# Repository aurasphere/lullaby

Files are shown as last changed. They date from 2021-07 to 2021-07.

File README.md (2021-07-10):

# Lullaby
Open source smart music box based on Arduino. It can store a melody inside the EEPROM which can later be played by pressing a button or by sending commands to the serial port. 

## Features
 - programmable, with persistent melody storage
 - supports 4 types of notes (whole, half, quarter, eighth) with relative rests, across 7 octaves. Notes can also be altered and dotted
 - customizable BPM
 - supports any time signature having a denominator of 2, 4 or 8 (e.g. 4/4, 2/2, 6/8...)
 - dedicated [mobile app](https://github.com/aurasphere/lullaby-mobile)
 - real-time playing (can be used as a piano or while composing the melody to store)
 - melody export (useful to save multiple melodies and restore them anytime)
 - optional led randomization on each note played

## Components
 - HC-05 Bluetooth Module
 - Active Buzzer
 - Arduino Nano (or any other compatible board)
 - Button
 - Resistance (1 needed, up to 5 more optional)
 - Leds (optional, up to 5) 
 
## Schematics

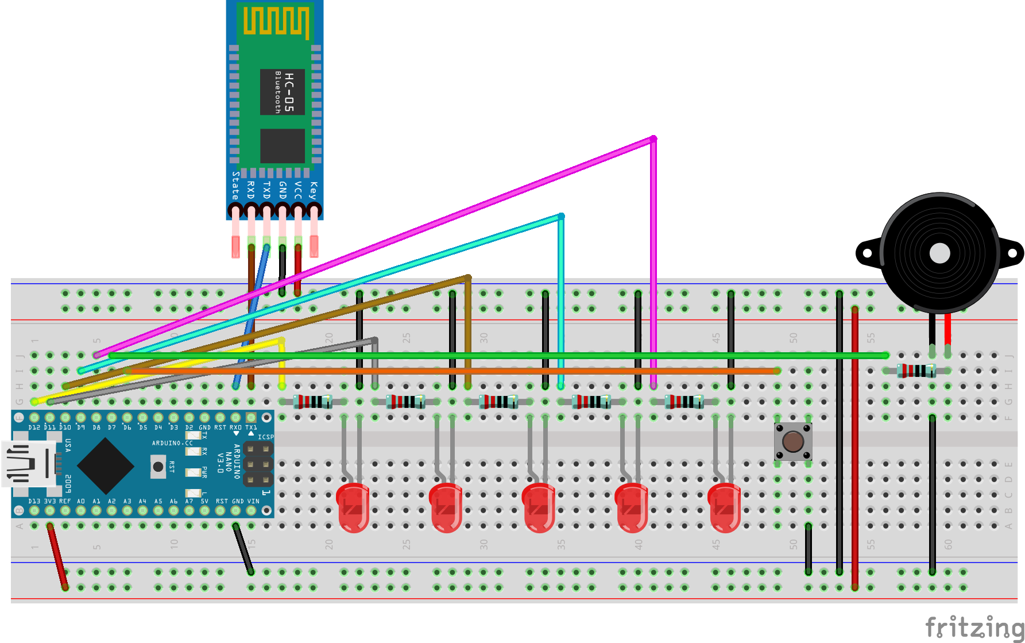
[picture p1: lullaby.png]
Schematics


## Commands

Communication is performed through serial port. Each command starts with an ASCII lowercase character and ends with a newline (```\n```). Some commands also require a melody argument (the encoding is described in the next paragraph). The available commands are the following:

 - **p**, plays the melody currently stored in EEPROM
 - **s(melody)**, saves the given melody into EEPROM
 - **d**, prints the details of the melody stored
 - **e**, exports the given melody in the Lullaby protocol
 - **n(melody)**, plays the given melody
 
## Melody Protocol

Lullaby uses a custom protocol based on hexadecimal bit stuffing. Each melody is represented by appending an header to a sequence of notes:

    <header><note><note><note>...
	
Both the header and the notes have a fixed length of 3 characters, so the length of each encoded melody is guaranteed to be a multiple of 3. The length of any melody is equal to 

    (encodedLength - 3) / 3.

### Header

The melody header contains the BPM and beat unit (e.g. the denominator of the time signature). The BPM is converted to 2 hexadecimal characters (using padding if needed) and then prepended to the beat unit, which is a digit between 1-3:
	  
| Time Signature | Beat Unit |
|:---:|:---:|
| */2 (2/2, 3/2, 4/2...) | 1 |
| */4 (2/4, 4/4, 5/4...) | 2 |
| */8 (3/8, 6/8, 9/8...) | 3 |
	    
For example, given a melody with a time signature of 4/4 and 120 BPM, the resulting header will be ```782```.
	    
### Notes

Each note is represented by 3 hexadecimal characters (1 + 1/2 bytes) containing the following informations (in order):
 - **pitch**, an integer ranging from 0 to 7 (3 bits) with 1 being C (Do) and 7 being B (Si). 0 is a rest
 - **duration**, an integer ranging from 0 to 4, (2 bits) indicating the note duration, according to the table below
 - **octave**, an integer ranging from 1 to 7 (3 bits)
 - **extended**, 0 (false) or 1 (true) (1 bit). Whether the note is dotted or not
 - **altered**, 0 (false) or 1 (true) (1 bit). Whether the note is altered (#) 

| Note |  Duration |
|:---:|:---:|
| Whole 𝅝	 | 0 |
| Half 	  𝅗𝅥 	 | 1 |
| Quarter ♩ | 2 |
| Eight ♪ | 3 |

The pitch, duration and octave are stored into the first byte (2 hex chars) meanwhile the extended and altered flags are stored in the last half byte (1 hex char). All the stuffing is big endian.

For example, we can calculate the value of the note G#5𝅗𝅥 as following:

    (5 << 5) + (1 << 3) + 5 =  173 = 0xAD // pitch + duration + octave, all compressed in 1 byte
    (0 << 3) + (1 << 2) = 4 = 0x4 // extended + altered, all compressed in 1/2 byte
    
And the final result is ```AD4```. So, taking the header we can attach the header we build before to have a complete melody, made up of only one note: ```782AD4```. 

To avoid unexpected behavior, Lullaby allows melodies up to 64 notes by default, but this can be easily configured by changing the ```MAX_MELODY_LENGTH``` property according to your device memory (both EEPROM and SRAM).

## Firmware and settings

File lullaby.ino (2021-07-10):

#include "pitches.h"
#include <avr/eeprom.h>

#define SERIALIZED_EOS_CHAR '\n'
#define SERIALIZED_NOTE_LENGTH 3
#define SERIALIZED_HEADER_LENGTH 3
#define MAX_MELODY_LENGTH 64
// See protocol_handler for info on how this is calculated
#define MESSAGE_BUFFER_SIZE 1 + SERIALIZED_HEADER_LENGTH + (MAX_MELODY_LENGTH * SERIALIZED_NOTE_LENGTH)

#define PRINT_MENU false
#define BAUD_RATE 9600

// Button
#define BUTTON 6
#define BUZZER 7

// Leds
#define WHITE 8
#define BLUE 9
#define GREEN 10
#define YELLOW 11
#define RED 12

// Stored on flash memory to save RAM.
const uint16_t NOTES[] PROGMEM = {NOTE_C1, NOTE_D1, NOTE_E1, NOTE_F1, NOTE_G1, NOTE_A1, NOTE_B1, NOTE_C2, NOTE_D2, NOTE_E2, NOTE_F2, NOTE_G2, NOTE_A2, NOTE_B2, NOTE_C3, NOTE_D3, NOTE_E3, NOTE_F3, NOTE_G3, NOTE_A3, NOTE_B3, NOTE_C4, NOTE_D4, NOTE_E4, NOTE_F4, NOTE_G4, NOTE_A4, NOTE_B4, NOTE_C5, NOTE_D5, NOTE_E5, NOTE_F5, NOTE_G5, NOTE_A5, NOTE_B5, NOTE_C6, NOTE_D6, NOTE_E6, NOTE_F6, NOTE_G6, NOTE_A6, NOTE_B6, NOTE_C7, NOTE_D7, NOTE_E7, NOTE_F7, NOTE_G7, NOTE_A7, NOTE_B7};
const uint16_t NOTES_ALTERED[] PROGMEM = {NOTE_CS1, NOTE_DS1, NOTE_E1, NOTE_FS1, NOTE_GS1, NOTE_AS1, NOTE_B1, NOTE_CS2, NOTE_DS2, NOTE_E2, NOTE_FS2, NOTE_GS2, NOTE_AS2, NOTE_B2, NOTE_CS3, NOTE_DS3, NOTE_E3, NOTE_FS3, NOTE_GS3, NOTE_AS3, NOTE_B3, NOTE_CS4, NOTE_DS4, NOTE_E4, NOTE_FS4, NOTE_GS4, NOTE_AS4, NOTE_B4, NOTE_CS5, NOTE_DS5, NOTE_E5, NOTE_FS5, NOTE_GS5, NOTE_AS5, NOTE_B5, NOTE_CS6, NOTE_DS6, NOTE_E6, NOTE_FS6, NOTE_GS6, NOTE_AS6, NOTE_B6, NOTE_CS7, NOTE_DS7, NOTE_E7, NOTE_FS7, NOTE_GS7, NOTE_AS7, NOTE_B7};

struct Note {
  uint8_t pitch : 3;
  uint8_t duration : 2;
  uint8_t octave : 3;
  boolean extended : 1;
  boolean altered : 1;
};

struct MelodyInfo {
  uint8_t bpm;
  uint8_t beatUnit;
  uint16_t length;
};

void setup() {
  // Open serial for communication.
  Serial.begin(BAUD_RATE);

  if (PRINT_MENU) {
    printMenu();
  }

  // Inizializes LEDS (if available)
  for (uint8_t i = WHITE; i <= RED; i++) {
    pinMode(i, OUTPUT);
  }

  // Inizializes the button
  pinMode(BUTTON, INPUT_PULLUP);
}

void playMelody(Note* melody, MelodyInfo melodyInfo) {
  uint16_t beatMillis = 60000 / melodyInfo.bpm;
  for (uint8_t i = 0; i < melodyInfo.length; i++) {
    Note note = melody[i];
    uint16_t duration = beatMillis * pow(2, note.duration - melodyInfo.beatUnit) * (note.extended ? 1.5 : 1);

    // Pitch of 0 is a rest.
    if (note.pitch == 0) {
      delay(duration);
      clearLeds();
      continue;
    }

    uint16_t pitch = pgm_read_word((note.altered ? NOTES_ALTERED : NOTES) + ((note.pitch - 1)  + (7 * (note.octave - 1))));

    // Plays a note.
    tone(BUZZER, pitch, duration);

    randomizeLeds();

    // Plays the note for the specified duration.
    delay(duration);
  }
  delete[] melody;
  clearLeds();
}


void playMelody() {
  MelodyInfo melodyInfo = loadMelodyInfoFromEeprom();
  Note melody[melodyInfo.length];
  loadMelodyFromEeprom(melodyInfo, melody);
  playMelody(melody, melodyInfo);
}

void loop() {

  // Handles a menu selection.
  if (Serial.available()) {
    handleMenuInput();
  }

  if (digitalRead(BUTTON) == LOW) {
    playMelody();
  }
}

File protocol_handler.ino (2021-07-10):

// Each melody is serialized in the following format:
// 3 chars (2 hex + 1|2|3) = MelodyInfo (or header), containing bpm and beatUnit
// 3 chars per note (hex)
// An header is represented by 3 characters:
// 2 HEX <- bpm
// 1|2|3 <- the beat unit
//        1 = */2 (half note)
//        2 = */4 (quarter note)
//        3 = */8 (eight note)
// Each note is represented by 3 HEX char with the following content:
// 3 bit <- note (0 to 7, 0 is for a rest)
// 2 bit <- duration (0 to 4, see below)
// 3 bit <- octave (1 to 7)
// 1 bit <- extended (true or false)
// 1 bit <- altered (true or false)
// 2 bit <- filler
// Supported durations:
// 0 -> whole note
// 1 -> half note
// 2 -> quarter note
// 3 -> eight note

// Deserialization functions.
MelodyInfo deserializeMelody(char* msgBuffer, Note* melodyBuffer) {
  uint16_t melodyLength = 0;

  // Parses the header first
  char header[4] = {msgBuffer[1], msgBuffer[2], msgBuffer[3]};
  MelodyInfo melodyInfo = deserializeHeader(header);

  // Parses the single notes.
  char nextChar = msgBuffer[4];
  while (nextChar != NULL) {
    uint8_t notePointer = (melodyLength * 3) + 4;
    char noteChar[5] = {msgBuffer[notePointer], msgBuffer[notePointer + 1] , msgBuffer[notePointer + 2]};
    melodyBuffer[melodyLength] = deserializeNote(noteChar);
    melodyLength++;
    nextChar = msgBuffer[notePointer + 3];
  }

  melodyInfo.length = melodyLength;
  return melodyInfo;
}

Note deserializeNote(char* note) {
  char firstByteArray[3] = {note[0], note[1]};
  char secondByteArray[2] = {note[2]};
  uint8_t firstByte = (uint8_t) strtol(firstByteArray, NULL, 16);
  uint8_t secondByte = (uint8_t) strtol(secondByteArray, NULL, 16);
  return  (Note) {
    (firstByte & (0b111 << 5)) >> 5,
    (firstByte & (0b11 << 3)) >> 3,
    firstByte & 0b111,
    (secondByte & (1 << 3)) != 0,
    (secondByte & (1 << 2)) != 0
  };
}

MelodyInfo deserializeHeader(char* header) {
  char bpmHex[3] = {header[0], header[1]};
  uint8_t bpm = (uint8_t) strtol(bpmHex, NULL, 16);
  uint8_t beatNote = (uint8_t) strtol(&header[2], NULL, 10);
  return (MelodyInfo) {
    bpm, beatNote, 0
  };
}

// Serialization functions.
void serializeMelody(MelodyInfo melodyInfo, Note* melodyBuffer, char* serializedMelody) {
  char buffer[4];
  serializeHeader(melodyInfo, buffer);
  memcpy(serializedMelody, buffer, sizeof(char) * 3);

  // Serializes the notes.
  for (uint16_t i = 0; i < melodyInfo.length; i++) {
    serializeNote(melodyBuffer[i], buffer);
    memcpy(serializedMelody + 3 * (i + 1), buffer, sizeof(char) * 3);
  }
  // Adds a null terminator to end the string
  serializedMelody[3 * (melodyInfo.length + 1)] = NULL;
}

void serializeNote(Note note, char* serializedNote) {
  uint8_t firstByteValue = (note.pitch << 5) + (note.duration << 3) + note.octave;
  uint8_t secondByteValue = (note.extended ? 1 << 3 : 0) + (note.altered ? 1 << 2 : 0);
  sprintf(serializedNote, "%02x%x", firstByteValue, secondByteValue);
  serializedNote[3] = NULL;
}

void serializeHeader(MelodyInfo melodyInfo, char* serializedHeader) {
  sprintf(serializedHeader, "%02x%d", melodyInfo.bpm, melodyInfo.beatUnit);
}

// Util functions (deprecated)
uint8_t applyMask(uint8_t byteVal, uint8_t index, uint8_t bitsToMask) {
  uint16_t mask = 1;
  for (uint8_t i = 0; i < bitsToMask - 1; i++, mask = mask * 10 + 1);
  return (byteVal & (mask << index)) >> index;
}

boolean isBitSet(uint8_t byteVal, uint8_t index) {
  return (byteVal & (1 << index)) != 0;
}

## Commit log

2021-07-10 Moved from Arduino projects.
2021-07-10 Added schematics and fixed docs.
    [lullaby.fzz]
2021-07-10 Bug fixes and optimizations.
    [eeprom_interface.ino, lullaby.ino, protocol_handler.ino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]
